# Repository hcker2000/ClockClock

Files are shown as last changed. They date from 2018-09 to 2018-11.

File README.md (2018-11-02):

# ClockClock
---
## Features
* Daylight alarm via led strip will start to brighten 15 minutes before scheduled alarm time
* Bed Shaker will start 1 minute before scheduled alarm time
* Buzzer will start at scheduled alarm time
* Alarm finishes one minute after scheduled alarm time
* WiFi setup/config
## Hardware
Currently this is being developed on a wemos D1 and a 128x64 OLED display. I have mounted the Voltage Regulator on headers to give it some breathing room. Please ignore the flux in the pictures.
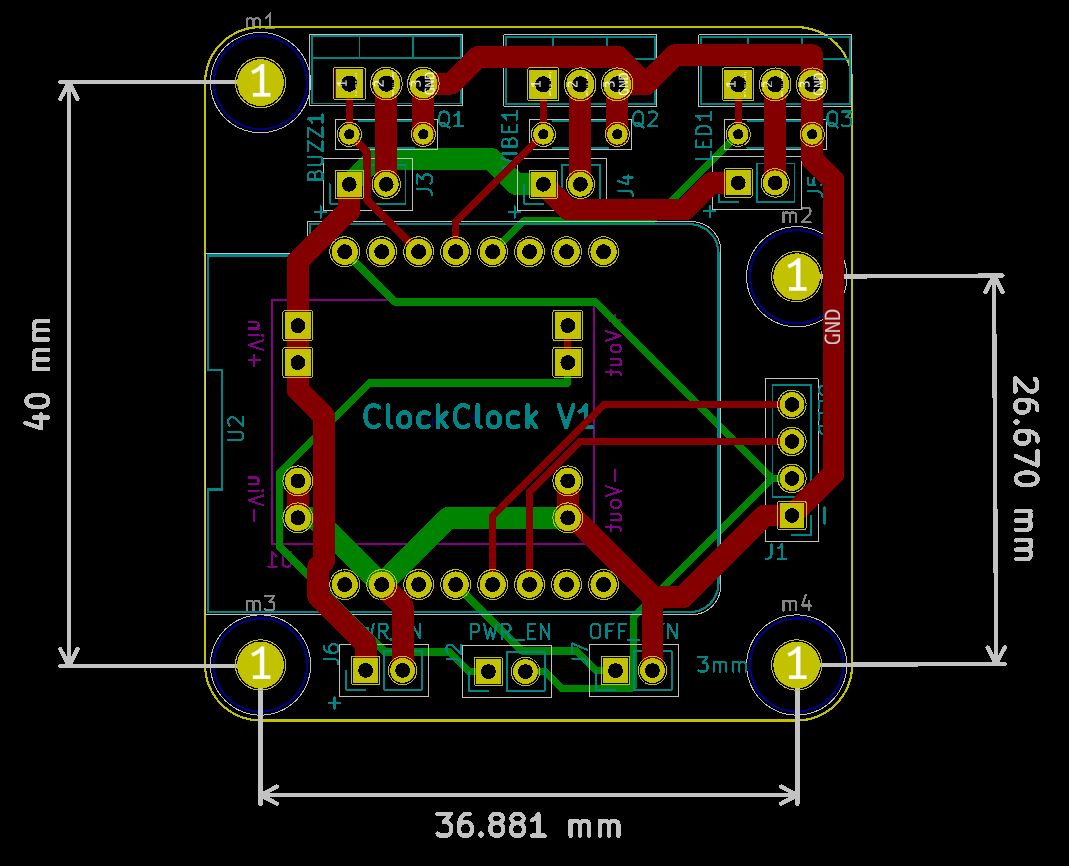
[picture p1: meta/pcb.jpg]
PCB

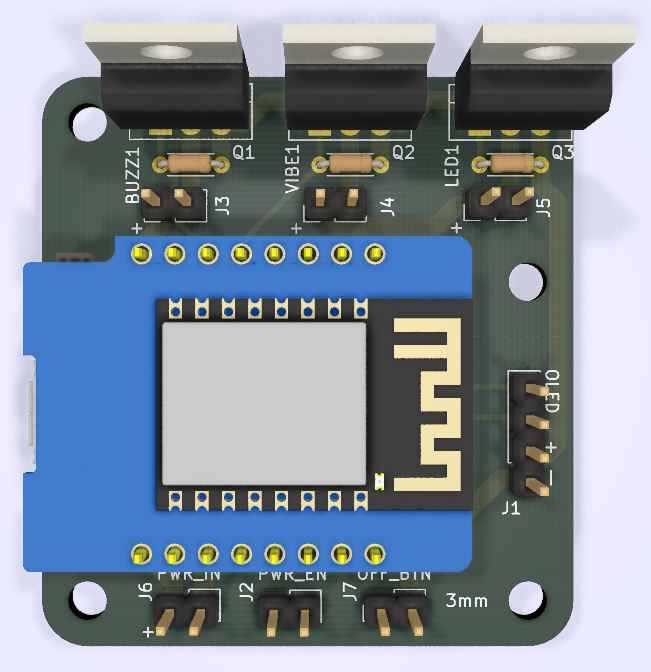
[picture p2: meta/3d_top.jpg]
3dtop

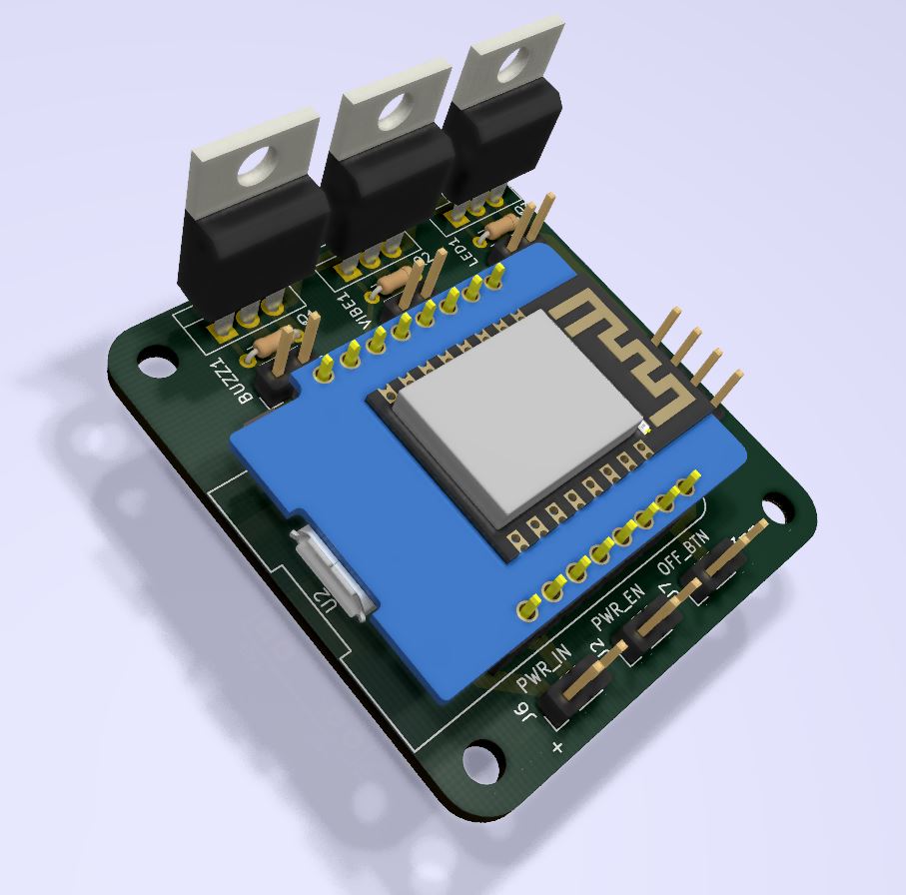
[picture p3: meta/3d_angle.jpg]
32angle

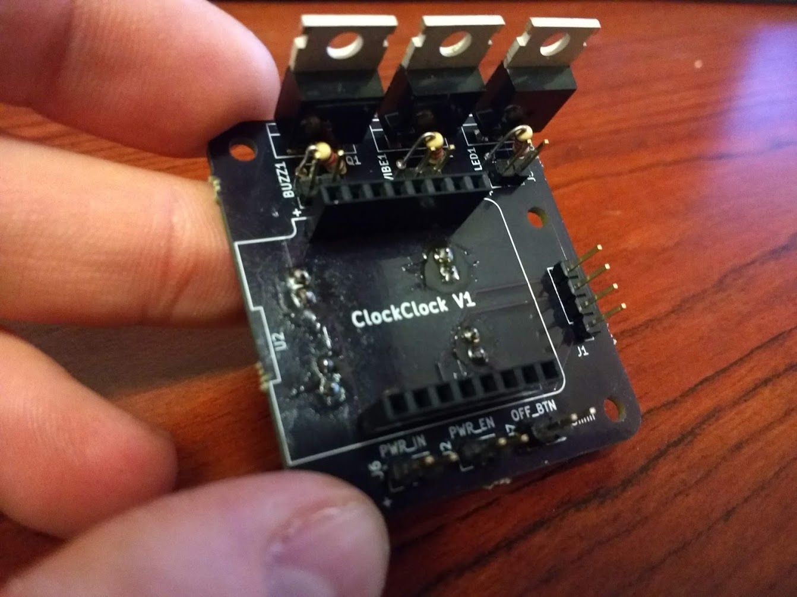
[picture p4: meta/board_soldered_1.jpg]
board_side_1

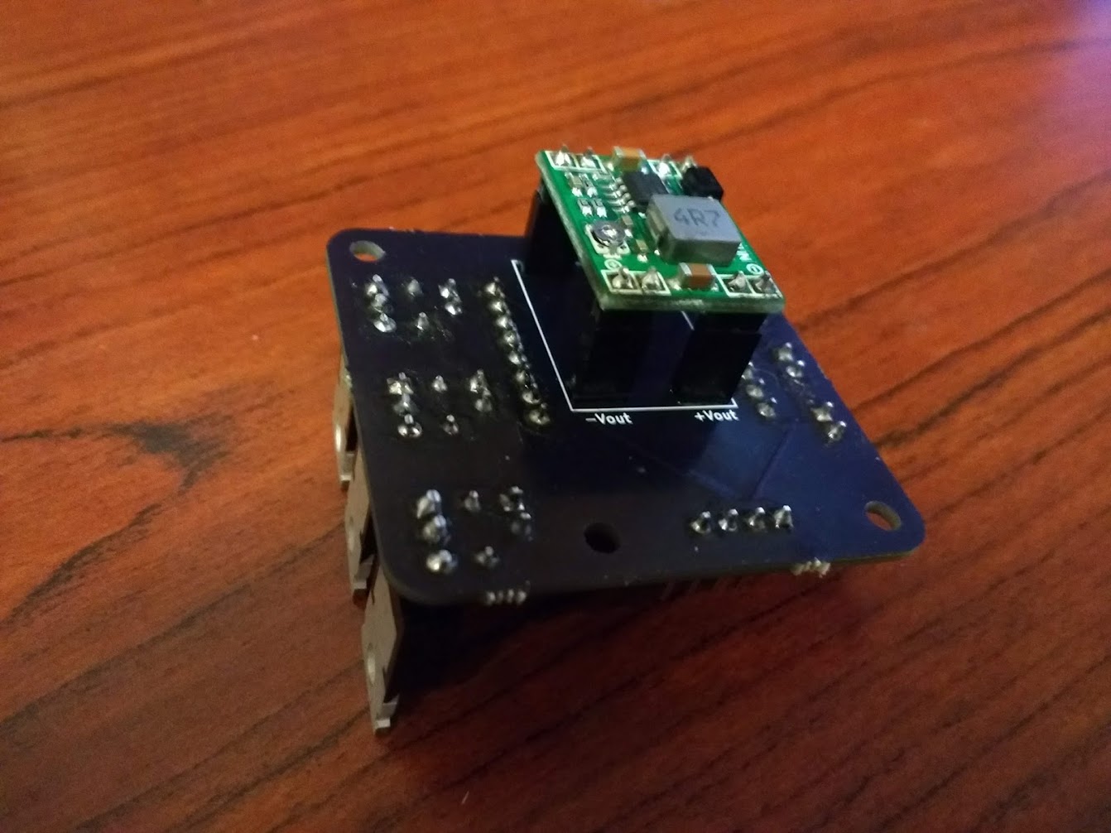
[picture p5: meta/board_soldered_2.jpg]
board_side_2

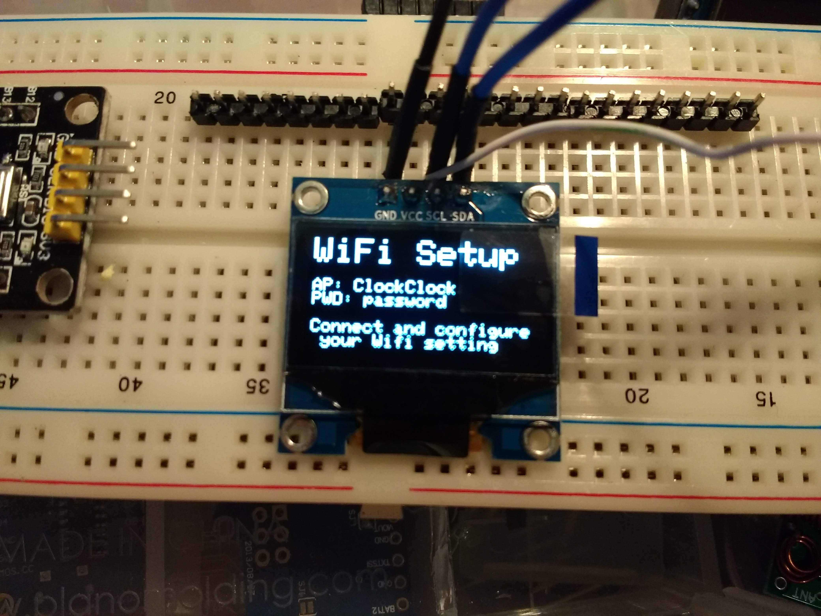
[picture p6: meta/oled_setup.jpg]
oled_setup

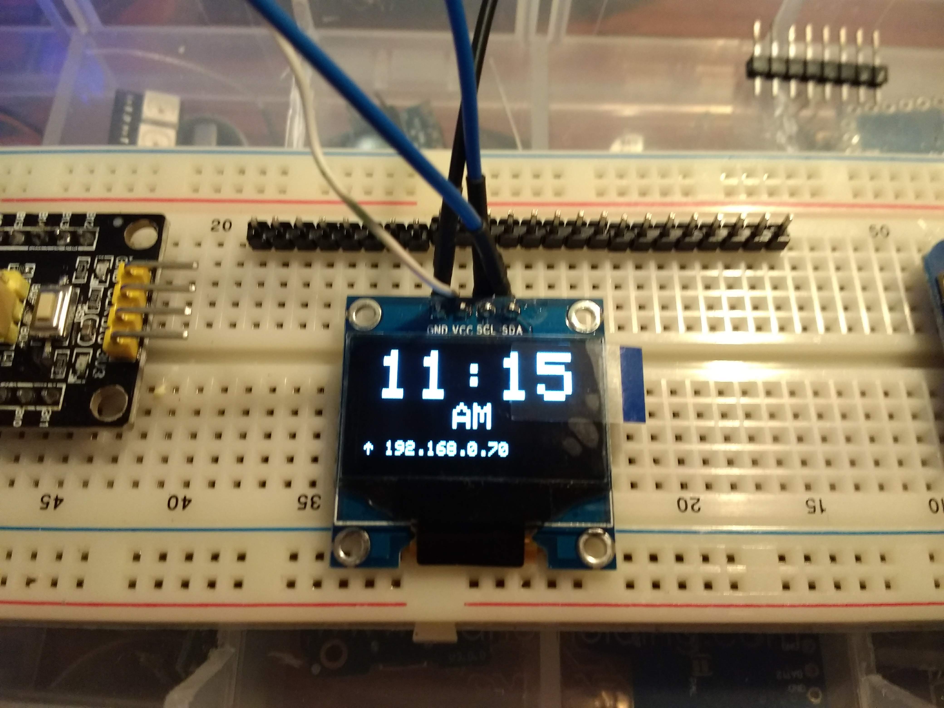
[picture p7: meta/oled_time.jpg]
oled_time

### Libraries
* Time is kept in sync via NTP lib at [https://github.com/PaulStoffregen/Time](https://github.com/PaulStoffregen/Time)
* Timezone/Daylight savings time are handled via TimeZone lib at [https://github.com/JChristensen/Timezone](https://github.com/JChristensen/Timezone)
* WiFi setup/config is provided by the amazing WiFi Config lib at [https://github.com/tzapu/WiFiManager](https://github.com/tzapu/WiFiManager)
* OLED Display is provided by [https://github.com/stblassitude/Adafruit_SSD1306_Wemos_OLED](https://github.com/stblassitude/Adafruit_SSD1306_Wemos_OLED)

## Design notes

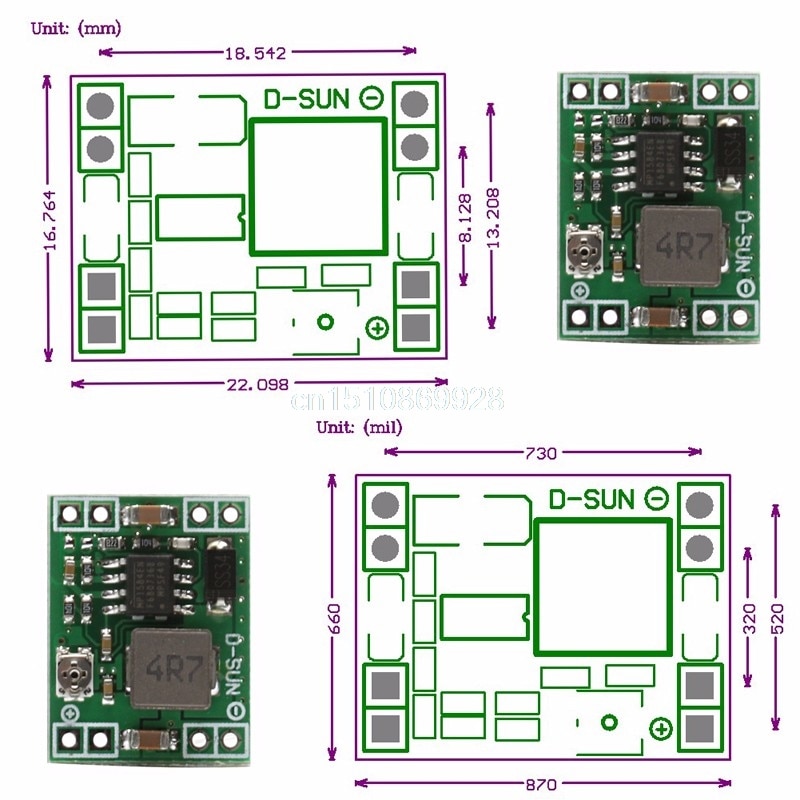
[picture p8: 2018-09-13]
meta/variable_vreg_board.jpg

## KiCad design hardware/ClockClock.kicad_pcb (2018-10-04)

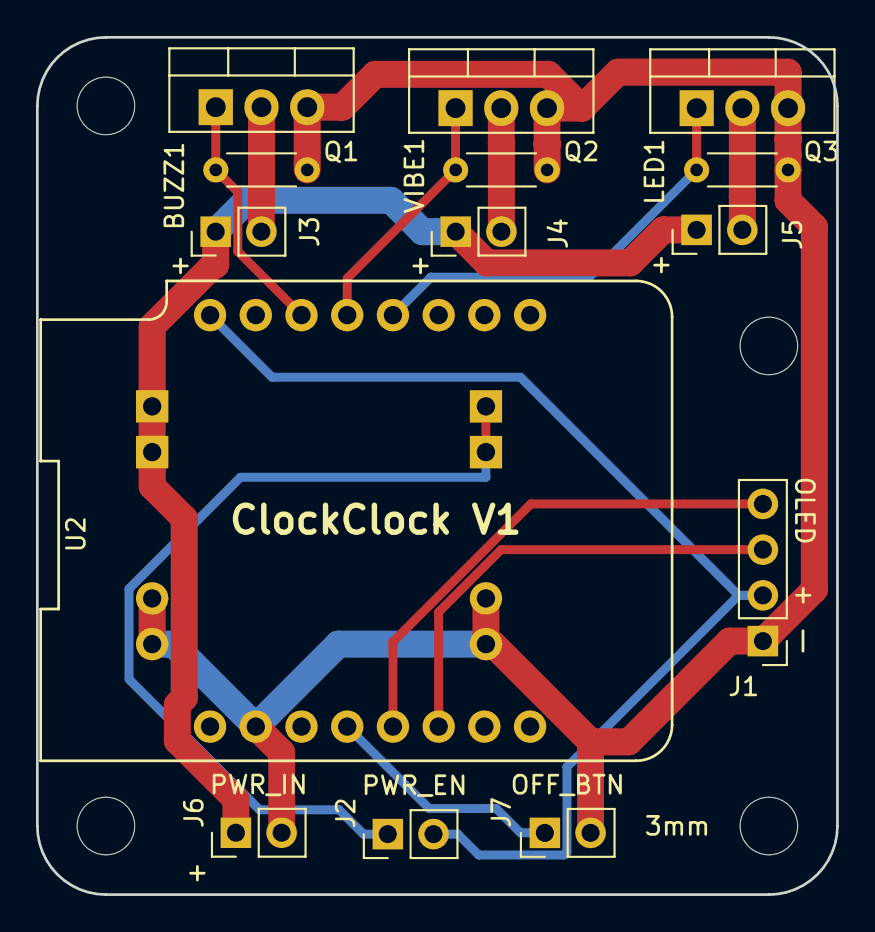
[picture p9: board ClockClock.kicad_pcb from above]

Board: 2 copper layers, 44.5 x 47.6 mm, 19 parts (1 on the bottom side), 13 nets.

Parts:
BUZZ1: 10k; R_Axial_DIN0204_L3.6mm_D1.6mm_P5.08mm_Horizontal
J1: OLED; PinHeader_1x04_P2.54mm_Vertical
J2: PWR_EN; PinHeader_1x02_P2.54mm_Vertical
J3: BUZZ_CON; PinHeader_1x02_P2.54mm_Vertical
J4: VIBE_CON; PinHeader_1x02_P2.54mm_Vertical
J5: LED_CON; PinHeader_1x02_P2.54mm_Vertical
J6: +12V_IN; PinHeader_1x02_P2.54mm_Vertical
J7: OFF_BTN; PinHeader_1x02_P2.54mm_Vertical
LED1: 10k; R_Axial_DIN0204_L3.6mm_D1.6mm_P5.08mm_Horizontal
Q1, Q2, Q3: IRLZ44N; TO-220-3_Vertical
U1: 3a_dcdc_vreg_board; 8_pin_header_mount
U2: WeMos_mini; wemos-d1-mini-with-pin-header-and-connector
VIBE1: 10k; R_Axial_DIN0204_L3.6mm_D1.6mm_P5.08mm_Horizontal
m1, m2, m3, m4: MountingHole_3.2mm_M3

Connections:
+12V: J3.1, J4.1, J5.1, J6.1, U1.5, U1.7
GND: BUZZ1.2, J1.1, J6.2, J7.2, LED1.2, Q1.3, Q2.3, Q3.3, U1.1, U1.2, U1.3, U1.4, U2.2, VIBE1.2
unnamed: BUZZ1.1, Q1.1, U2.14
unnamed: J1.2, J2.2, U2.16
unnamed: J1.3, U2.6
unnamed: J1.4, U2.5
unnamed: J2.1, U1.6, U1.8
unnamed: J3.2, Q1.2
unnamed: J4.2, Q2.2
unnamed: J5.2, Q3.2
unnamed: J7.1, U2.4
unnamed: LED1.1, Q3.1, U2.12
unnamed: Q2.1, U2.13, VIBE1.1

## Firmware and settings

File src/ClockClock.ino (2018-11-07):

#include "Config.h"
#include "Html.h"
#include <TimeLib.h>  //https://github.com/PaulStoffregen/Time
#include <Timezone.h> //https://github.com/JChristensen/Timezone
#include <ESP8266WiFi.h>
#include <WiFiUdp.h>
#include <DNSServer.h>   //Local DNS Server used for redirecting all requests to the configuration portal
#include <WiFiManager.h> //https://github.com/tzapu/WiFiManager WiFi Configuration Magic
#include "Display.h"
#include "Alarm.h"

Display oledDisplay;
Alarm alarm;
Html htmlLib;

WiFiUDP Udp;
unsigned int localPort = 8888; // local port to listen for UDP packets

TimeChangeRule dstStart = {"EDT", Second, Sun, Mar, 2, -240}; //UTC - 4 hours
TimeChangeRule dstEnd = {"EST", First, Sun, Nov, 2, -300};    //UTC - 5 hours
Timezone localTimeZone(dstStart, dstEnd);

time_t getNtpTime();

void sendNTPpacket(IPAddress &address);

void configModeCallback(WiFiManager *myWiFiManager)
{
  Serial.println("Entered config mode");
  Serial.println(WiFi.softAPIP());
  //if you used auto generated SSID, print it
  Serial.println(myWiFiManager->getConfigPortalSSID());
  oledDisplay.showWifiInstructions(myWiFiManager->getConfigPortalSSID());
}

void setup()
{
  Serial.begin(9600);
  oledDisplay.setup();
  alarm.setup();
  delay(250);
  Serial.println("ClockClock the alarm clock");

  WiFiManager wifiManager;
  wifiManager.setAPCallback(configModeCallback);

  // This will block untell the wifi connection has been configured and/or connected
  if (!wifiManager.autoConnect("ClockClock", "password"))
  {
    Serial.println("failed to connect and hit timeout");
    //reset and try again, or maybe put it to deep sleep
    ESP.reset();
    delay(1000);
  }

  Serial.println("Starting UDP");
  Udp.begin(localPort);
  Serial.print("Local port: ");
  Serial.println(Udp.localPort());
  Serial.println("waiting for sync");
  setSyncProvider(getNtpTime);
  setSyncInterval(5); // update from ntp every 5 seconds

  htmlLib.setup();
}

void loop()
{
  if (WiFi.status() == WL_CONNECTED)
  {
    IPAddress myIP = WiFi.localIP();
    String ipStr = String(myIP[0]) + "." + String(myIP[1]) + "." + String(myIP[2]) + "." + String(myIP[3]);
    oledDisplay.ip = ipStr;
  }
  else
  {
    oledDisplay.ip = "";
  }

  htmlLib.loop();

  if (timeStatus() != timeNotSet)
  {
    time_t localTime = localTimeZone.toLocal(now());
    oledDisplay.inverted = alarm.running();
    oledDisplay.loop(localTime);
    alarm.loop(localTime);
  }
}

/*-------- NTP code ----------*/

const int NTP_PACKET_SIZE = 48;     // NTP time is in the first 48 bytes of message
byte packetBuffer[NTP_PACKET_SIZE]; //buffer to hold incoming & outgoing packets

time_t getNtpTime()
{
  IPAddress ntpServerIP; // NTP server's ip address

  while (Udp.parsePacket() > 0)
    ; // discard any previously received packets
  Serial.println("Transmit NTP Request");
  // get a random server from the pool
  WiFi.hostByName(ntpServerName, ntpServerIP);
  Serial.print(ntpServerName);
  Serial.print(": ");
  Serial.println(ntpServerIP);
  sendNTPpacket(ntpServerIP);
  uint32_t beginWait = millis();
  while (millis() - beginWait < 1500)
  {
    int size = Udp.parsePacket();
    if (size >= NTP_PACKET_SIZE)
    {
      oledDisplay.ntpStatus(true);
      Udp.read(packetBuffer, NTP_PACKET_SIZE); // read packet into the buffer
      unsigned long secsSince1900;
      // convert four bytes starting at location 40 to a long integer
      secsSince1900 = (unsigned long)packetBuffer[40] << 24;
      secsSince1900 |= (unsigned long)packetBuffer[41] << 16;
      secsSince1900 |= (unsigned long)packetBuffer[42] << 8;
      secsSince1900 |= (unsigned long)packetBuffer[43];

      setSyncInterval(300); // update from ntp every 5 minutes
      return secsSince1900 - 2208988800UL + timeZone * SECS_PER_HOUR;
    }
  }
  oledDisplay.ntpStatus(false);

  setSyncInterval(5); // update from ntp every 5 seconds
  return 0;           // return 0 if unable to get the time
}

// send an NTP request to the time server at the given address
void sendNTPpacket(IPAddress &address)
{
  // set all bytes in the buffer to 0
  memset(packetBuffer, 0, NTP_PACKET_SIZE);
  // Initialize values needed to form NTP request
  // (see URL above for details on the packets)
  packetBuffer[0] = 0b11100011; // LI, Version, Mode
  packetBuffer[1] = 0;          // Stratum, or type of clock
  packetBuffer[2] = 6;          // Polling Interval
  packetBuffer[3] = 0xEC;       // Peer Clock Precision
  // 8 bytes of zero for Root Delay & Root Dispersion
  packetBuffer[12] = 49;
  packetBuffer[13] = 0x4E;
  packetBuffer[14] = 49;
  packetBuffer[15] = 52;
  // all NTP fields have been given values, now
  // you can send a packet requesting a timestamp:
  Udp.beginPacket(address, 123); //NTP requests are to port 123
  Udp.write(packetBuffer, NTP_PACKET_SIZE);
  Udp.endPacket();
}

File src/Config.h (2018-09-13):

#ifndef Config_h
#define Config_h
// NTP Servers:
//static const char ntpServerName[] = "us.pool.ntp.org";
static const char ntpServerName[] = "time.nist.gov";
//static const char ntpServerName[] = "time-a.timefreq.bldrdoc.gov";
//static const char ntpServerName[] = "time-b.timefreq.bldrdoc.gov";
//static const char ntpServerName[] = "time-c.timefreq.bldrdoc.gov";

const int timeZone = 0; // This will be handled by the TimeZone lib so we need to supply that with UTC

static const char *stringDays[] = {"Sunday", "Monday", "Tuesday", "Wednesday", "Thursday", "Friday", "Saturday"};

const unsigned int ALARM_TOTAL = 14;
const unsigned int DISABLED_STATE = 0;
const unsigned int ENABLED_STATE = 1;
const unsigned int DELETED_STATE = 2;
const unsigned int START_FADE = 15;                                       // Controlls how long before the alarm that the leds will start fading in. This is in minutes
const unsigned long TIME_BETWEEN_LED_STEPS = (START_FADE * 60000) / 1024; // Milliseconds between led levels
static const uint8_t OFF_PIN = D3;
static const uint8_t LED_PIN = D5;
static const uint8_t VIBE_PIN = D6;
static const uint8_t BUZZER_PIN = D7;

#endif

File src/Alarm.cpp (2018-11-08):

#include "Alarm.h"
#include "Config.h"
#include "PadDigit.h"
#include <Arduino.h>
#include <FunctionalInterrupt.h>
#include <EEPROM.h>
#include <TimeLib.h> //https://github.com/PaulStoffregen/Time

Alarm::Alarm()
{
}

void Alarm::setup()
{
    EEPROM.begin(56);

    // Setup EEPROM values if need be
    for (unsigned int i = 0; i < ALARM_TOTAL; i++)
    {
        int alarmEnabledIndex = i * 4;
        eepromByte = EEPROM.read(alarmEnabledIndex);
        if (eepromByte != 0 && eepromByte != 1 && eepromByte != DELETED_STATE)
        {
            Serial.println("Setting up Alarm: " + (String)i);
            EEPROM.write(alarmEnabledIndex, DELETED_STATE);
            EEPROM.commit();
        }
    }

    // Setup output pins
    pinMode(LED_PIN, OUTPUT);
    pinMode(VIBE_PIN, OUTPUT);
    pinMode(BUZZER_PIN, OUTPUT);

    // Setup input pins
    pinMode(OFF_PIN, INPUT_PULLUP);

    analogWrite(LED_PIN, 0);
    digitalWrite(VIBE_PIN, LOW);
    digitalWrite(BUZZER_PIN, LOW);

    attachInterrupt(OFF_PIN, std::bind(&Alarm::interruptHandler, this), FALLING);
}

void Alarm::loop(time_t &t)
{
    localTime = t;

    if (minute(localTime) != minute(lastUpdate))
    {
        lastUpdate = localTime;
        check();
    }

    process();
}

void Alarm::check()
{
    if (alarmRunning == false)
    {
        for (unsigned int i = 0; i < ALARM_TOTAL; i++)
        {
            int alarmEnabledIndex = i * 4;
            eepromByte = EEPROM.read(alarmEnabledIndex); // I am keeping the enabled byte at the head of each "page". A page being four bytes consisting of enabled, day, hour, minute
            if (eepromByte == ENABLED_STATE)
            {
                byte aDay = EEPROM.read(alarmEnabledIndex + 1);
                byte aHour = EEPROM.read(alarmEnabledIndex + 2);
                byte aMinute = EEPROM.read(alarmEnabledIndex + 3);

                // Check to see if we need to handle wraping back to the last minute
                int i = (aMinute - START_FADE);
                if (i < 0)
                {
                    aMinute = 60 + i; // adding a negative number

                    // Roll back the hour
                    if ((aHour - 1) < 0)
                    {
                        aHour = 23;

                        // Rollback Day
                        // Day is stored 1-7 rather than 0-6
                        if (aDay - 1 <= 0)
                        {
                            aDay = 7;
                        }
                    }
                }

                if (aDay == weekday(localTime))
                {
                    if (aHour == hour(localTime))
                    {
                        unsigned int startFadeSeconds = (START_FADE * 60);
                        if (aMinute == minute(localTime + startFadeSeconds))
                        {
                            Serial.println(PadDigit::format(hourFormat12(localTime)) + ":" + PadDigit::format(minute(localTime)));
                            Serial.println("Alarm Started!");
                            alarmRunning = true;
                            ledStartTime = localTime;
                            vibeStartTime = localTime + (startFadeSeconds - 60);
                            buzzerStartTime = vibeStartTime + 60;
                            alarmEndTime = buzzerStartTime + 60;
                        }
                    }
                }
            }
        }
    }
}

void Alarm::process()
{
    static unsigned long lastStepTime = millis();
    static unsigned long lastDigitalTime = millis();
    static bool isDigitalOn = false;

    if (alarmRunning == true)
    {
        if (localTime >= ledStartTime && ledLevel < 1024)
        {
            // Update leds
            if (millis() >= lastStepTime + TIME_BETWEEN_LED_STEPS)
            {
                lastStepTime = millis();
                ledLevel += 1;
                Serial.println("LED Level:" + (String)ledLevel);
                analogWrite(LED_PIN, ledLevel);
            }
        }

        if (localTime >= vibeStartTime || localTime >= buzzerStartTime)
        {
            if (millis() > (lastDigitalTime + 500))
            {
                lastDigitalTime += 500;

                if (isDigitalOn == true)
                {
                    isDigitalOn = false;

                    if (localTime >= vibeStartTime)
                    {
                        digitalWrite(VIBE_PIN, LOW);
                    }

                    if (localTime >= buzzerStartTime)
                    {
                        digitalWrite(BUZZER_PIN, LOW);
                    }
                }
                else
                {
                    isDigitalOn = true;

                    if (localTime >= vibeStartTime)
                    {
                        digitalWrite(VIBE_PIN, HIGH);
                    }

                    if (localTime >= buzzerStartTime)
                    {
                        digitalWrite(BUZZER_PIN, HIGH);
                    }
                }
            }
        }

        if (localTime >= alarmEndTime)
        {
            clear();
        }
    }
}

void Alarm::interruptHandler()
{
    static unsigned long last_interupt_time = 0;
    unsigned long now = millis();

    if (now - last_interupt_time > 100)
    {
        Serial.println("Alarm Off");
        clear();
    }

    last_interupt_time = now;
}

void Alarm::clear()
{
    alarmRunning = false;
    ledLevel = 0;
    analogWrite(LED_PIN, 0);
    digitalWrite(VIBE_PIN, LOW);
    digitalWrite(BUZZER_PIN, LOW);
}

bool Alarm::running()
{
    return alarmRunning;
}

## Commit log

2018-09-06 updated readme to reflect current dev setup
2018-09-11 updated pin asignments and started hardware
    [ClockClock.kicad_pcb, ClockClock.sch]
2018-09-12 Getting board design ready for printing
    [ClockClock-B.Cu.gbr, ClockClock-B.Mask.gbr, ClockClock-B.Paste.gbr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]
2018-09-13 directory clean up and better more finalized layout
    [ClockClock-B.Cu.gbr, ClockClock-B.Mask.gbr, ClockClock-B.Paste.gbr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]
2018-09-13 added code to handle an off button
2018-09-13 Finalized board layout and added some pictures to the info
    [ClockClock-B.Cu.gbr, ClockClock-B.Mask.gbr, ClockClock-B.Paste.gbr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]
2018-09-24 Updated some labels on the 3 amp voltage regulator
    [ClockClock-B.Cu.gbr, ClockClock-B.Mask.gbr, ClockClock-B.Paste.gbr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]
2018-09-25 updated readme with some pictures of the prototypes display
2018-10-04 Updated pcb image to include distances between mounting holes
2018-10-04 Missed saving the actual kicad pcb file
    [ClockClock.kicad_pcb]
2018-10-10 Added soldered board images
2018-11-06 fixed a spelling mistake
    [Alarm.cpp]
2018-11-06 Fixed a bug where the time zone was not being setup correctly
    [ClockClock.ino]
2018-11-07 Added code to invert the oled as soon as the alarm starts it run.
    [Alarm.cpp, ClockClock.ino, Display.cpp]
2018-11-08 Fixed a spelling mistake and lowered the debounce from 500 to 100ms
    [Alarm.cpp]

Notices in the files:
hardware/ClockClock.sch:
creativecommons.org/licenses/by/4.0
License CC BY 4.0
